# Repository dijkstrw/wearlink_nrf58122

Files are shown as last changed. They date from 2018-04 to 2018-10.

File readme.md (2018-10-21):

# Wearlink v2

## Introduction

While looking for a new winter coat I stumbled on a Taiwanese manufacturer
selling a black and blue winter coat with keys on the sleeve.

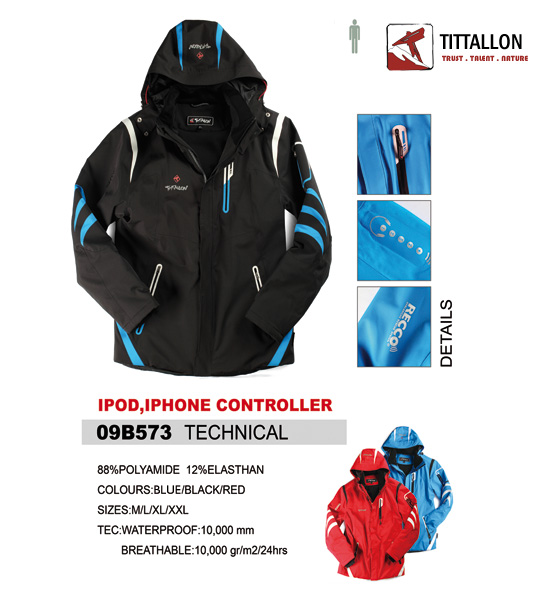
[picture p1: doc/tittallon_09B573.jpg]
Coat and keys


The keys legend betray their intended purpose: volume control, play/pause and
forward/reverse. I listen to podcasts on my android phone in the car and on the
bike, and this would make a great way to control those even when wearing
gloves!

It turns out that the real keypad is glued to the inside of the sleeve, just
under the outer coat layers. A ruggedized two-wire cable connected the keypad
to a 2.5mm TRS in the left chest pocket.

The keypad is manufactured by [FibreTronic](http://fibretronic.com) under the
moniker connectedwear. They sell a range of keypads (my coat has the
[KP2-5SH](http://fibretronic.com/connectedwear/KP25SH) ) and a range of
controllers that can be connected to the keypad. Naturally none of their
controllers work for me. A couple of years I built my
[first controller](https://github.com/dijkstrw/wearlink), and this project is
an update of that design with these requirements:

* No wiring between controller and phone. Making reliable connections between
  flexible wire and hard connectors is a hard problem. I have had to replace
  the connections many times, and have not found a good way to make them last
  years when wires can flex due to walking.

* No wiring means internal battery -- be frugal in power consumption.

* Default interface to the phone. Ideally no programming on the phone, because
  this somewhat guarantees project longevity.

## My design

A controller that pretends to be a usb keyboard and emits multimedia keys for
keypresses. Bluetooth is used to eliminate wires, and the mcu and pcb has been
designed for low power operation to make that battery go for months. I had
heard good things about Nordic, and went with the
[nRF51822](https://www.nordicsemi.com/eng/Products/Bluetooth-low-energy/nRF51822)
because:

* ARM Cortex M0

* Bluetooth Low Energy

* 128k flash at entry level (but read on)

* Onboard regulators, with a supply range between 1.8 and 3.6V

* JTAG programming using a four wire interface

### nRF51822

BLE is implemented using a soft-core that lives in the first half of the
flash. Your application configures the soft-core structures to get the type of
BLE interface you want, and the soft-core will call event-handlers to indicate
radio or hardware events.

The nRF51822 needs an antenna and careful layout. There are also ready made
boards that can be used as complete dropin modules, we use the S4AT here.

### ADC configuration / wakeup

Fibretronics wearlink is a string of push button (no) switches individually in
series with a resistor. When no button is pressed it is open circuit. When one
button is pressed, the resistance corresponding to that key is present between
the two feed wires.

Running the ADC will cause it to sample. Sampling looks like an input impedance
of ~390k, so to spare the battery the ADC needs to run only when BLE is
active. Q1 is used to make nice detectable falling edges at keypress to ensure
wakeup when not in a BLE conversation.

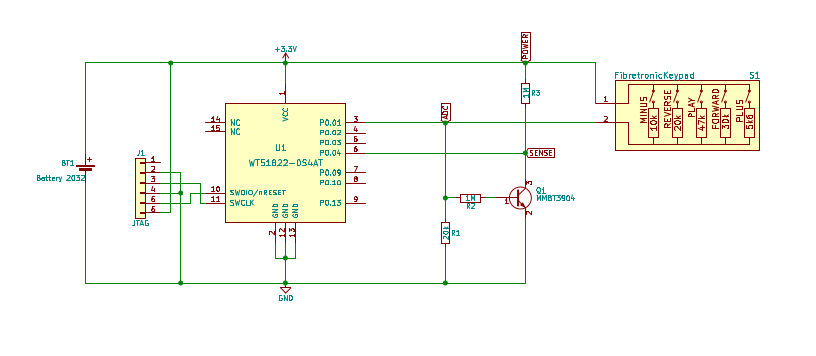
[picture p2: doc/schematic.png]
Kicad schematic


As the battery discharges our ADC input voltage will drop also. This is
compensated for by periodically measuring the battery voltage and taking that
into account when determining keys pressed.

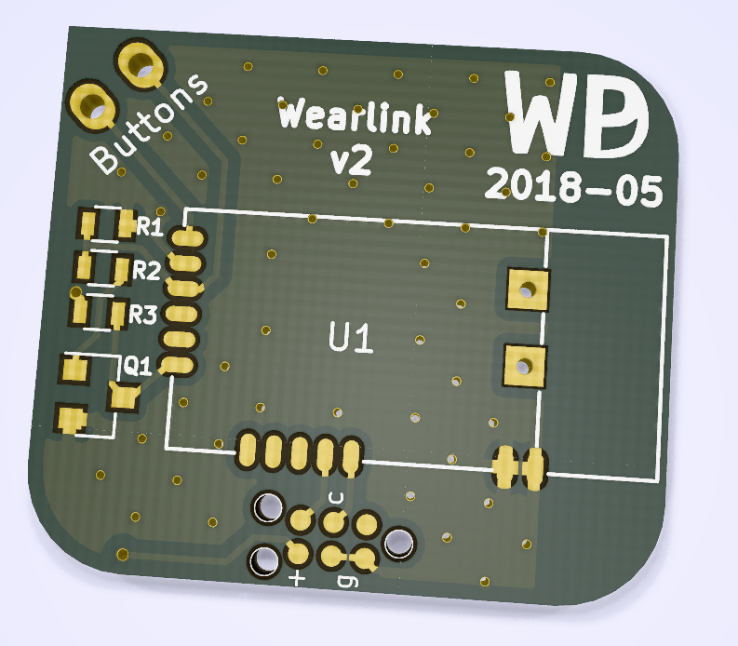
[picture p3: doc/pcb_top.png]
Top

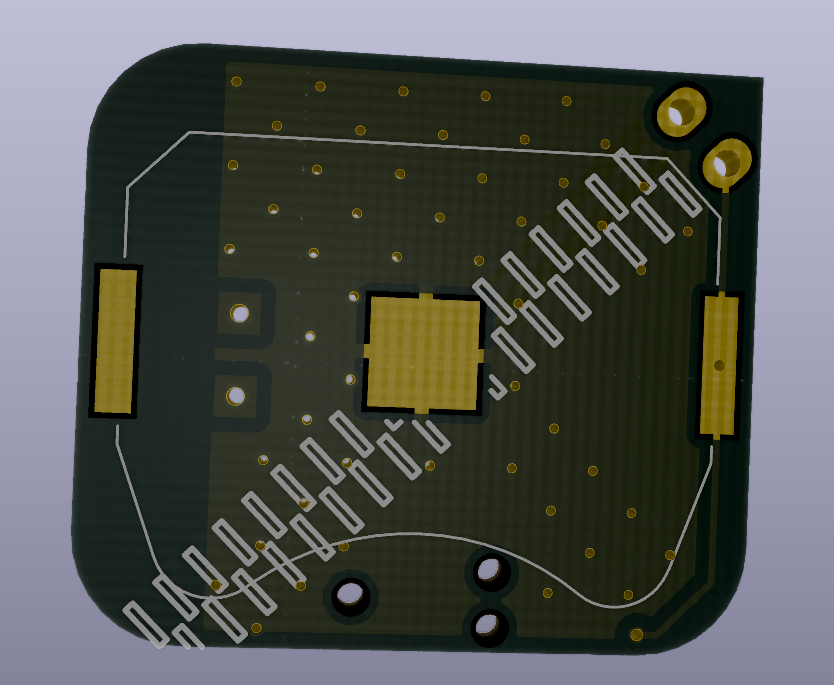
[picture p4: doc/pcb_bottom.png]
Bottom


Note that a TagConnect header is used for JTAG.

### BLE bonding

BLE pairing is stored in flash and reused at next bootup. To make the
controller forget all pairings press key combination PLAY, PLAY, PLAY, VOLUME
DOWN, VOLUME DOWN, VOLUME UP, VOLUME UP directly after controller wakeup.

## Directory structure

* `config` - board configuration files that define clock and peripheral
  configuration for the nrf51. Also the place where the linker file lives

* `doc` - pdf repository for used boards and ics

* `nrf51_sdk_10_0_0` - Download the [SDK](https://developer.nordicsemi.com/nRF5_SDK/nRF51_SDK_v10.x.x/nRF51_SDK_10.0.0_dc26b5e.zip) from Nordic and unzip here

* `schematic` - board schematic and pcb in Kicad

## Next time

* Current nRF51 carrier (S4AT) does not have a LXFT, so even more power can be saved
  next time by choosing or designing a board that does.

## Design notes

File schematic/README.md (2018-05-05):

WT51822-0S4AT taken from https://github.com/cyrozap/KiCad

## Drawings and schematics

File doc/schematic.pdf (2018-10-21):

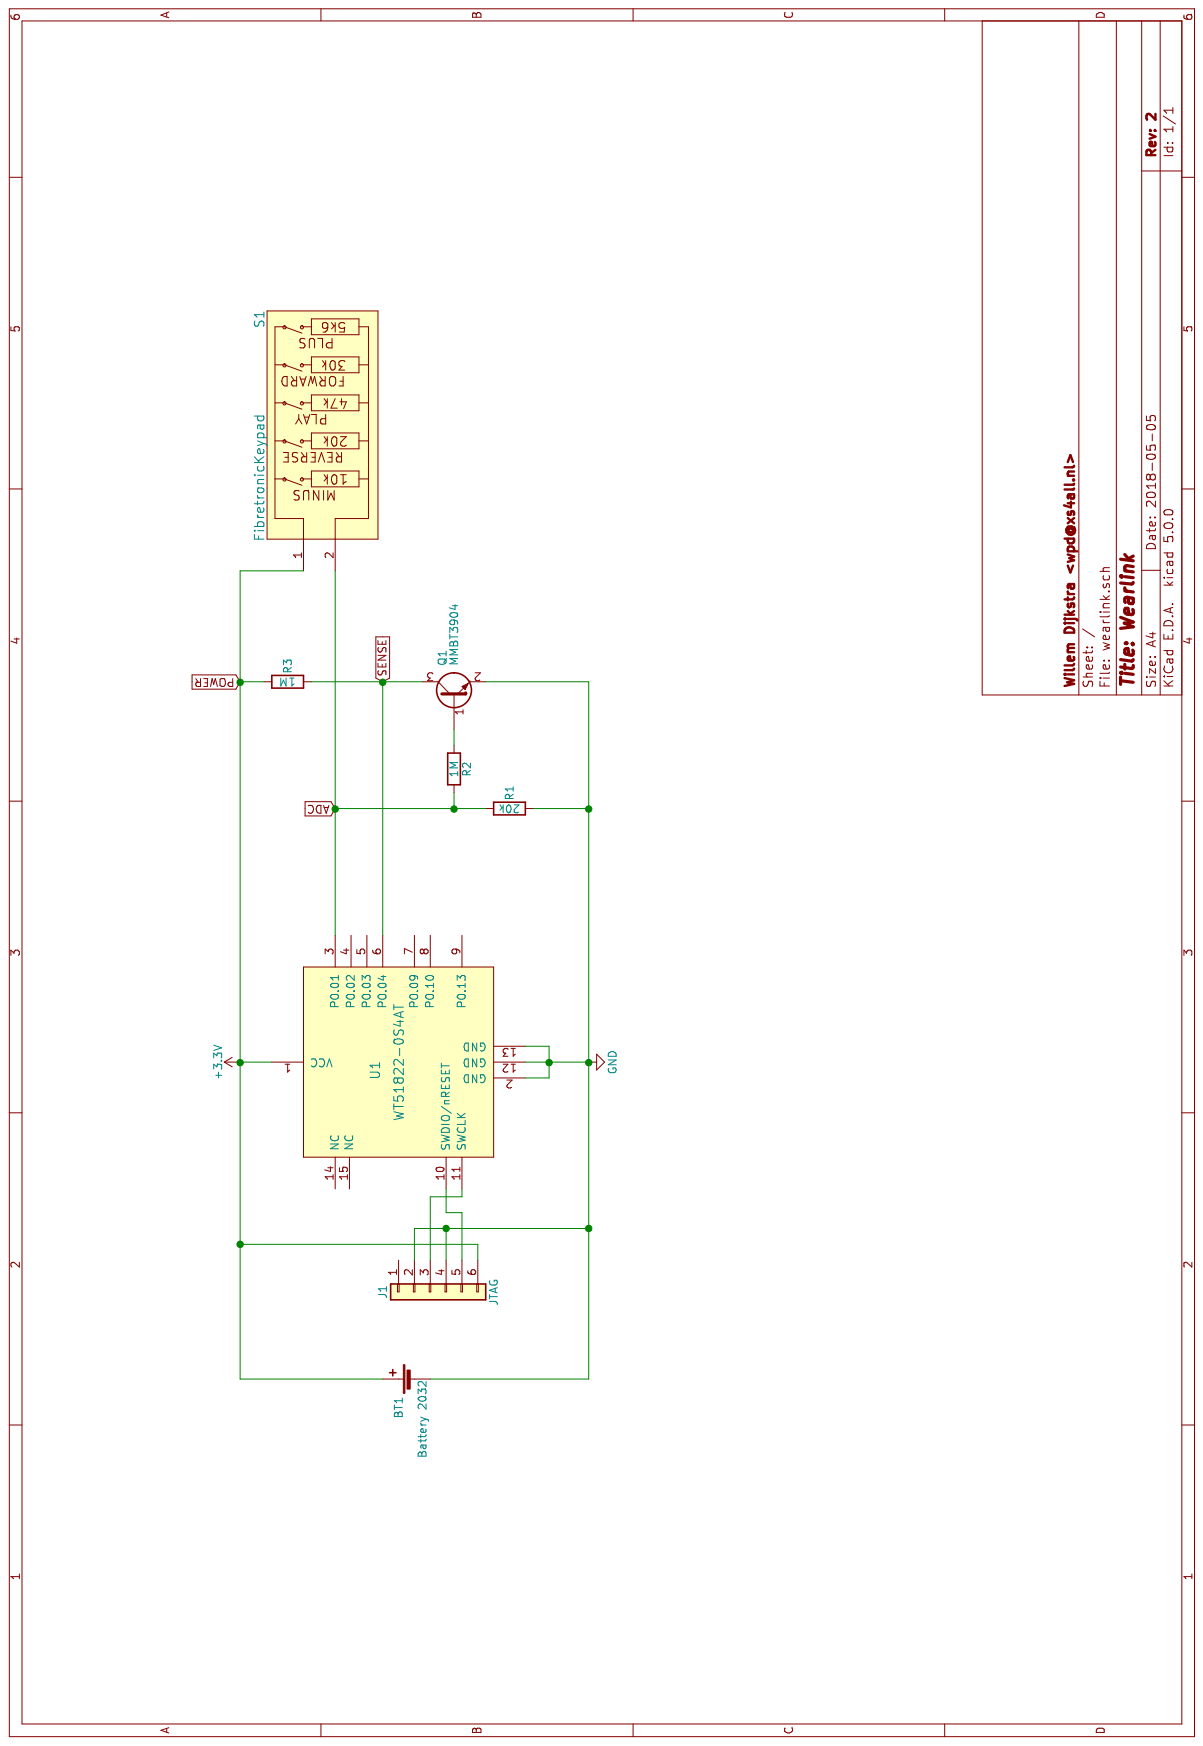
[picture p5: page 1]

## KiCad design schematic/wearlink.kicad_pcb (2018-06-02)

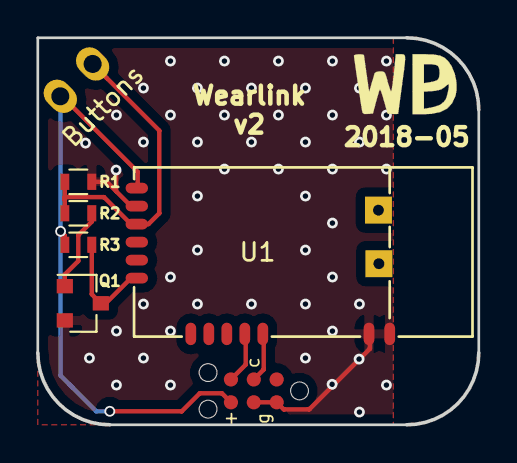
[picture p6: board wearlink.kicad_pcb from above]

Board: 2 copper layers, 24.5 x 21.5 mm, 8 parts (1 on the bottom side), 7 nets.

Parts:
BT1: Battery 2032; Keystone_3034_1x20mm-CoinCell
Buttons: FibretronicKeypad
J1: JTAG; TC2030-IDC-NL
Q1: MMBT3904; SOT-23
R1: 20k; R_0603
R2, R3: 1M; R_0603
U1: WT51822-0S4AT

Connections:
ADC: Buttons.2, R1.1, R2.2, U1.3
GND: BT1.2, J1.2, J1.4, Q1.2, R1.2, U1.2, U1.12, U1.13
unnamed: J1.3, U1.11
unnamed: J1.5, U1.10
unnamed: Q1.1, R2.1
POWER: BT1.1, Buttons.1, J1.6, R3.1, U1.1
SENSE: Q1.3, R3.2, U1.6

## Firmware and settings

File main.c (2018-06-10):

/* Copyright (c) 2018 Willem Dijkstra. All Rights Reserved.
 *
 * Consumer keys (media keys) using nrf51822 and Nordic SDK 10.0.0
 *
 * based on Nordic's ble_sdk_app_hids_keyboard_main sample file.
 *
 */

/* Copyright (c) 2012 Nordic Semiconductor. All Rights Reserved.
 *
 * The information contained herein is property of Nordic Semiconductor ASA.
 * Terms and conditions of usage are described in detail in NORDIC
 * SEMICONDUCTOR STANDARD SOFTWARE LICENSE AGREEMENT.
 *
 * Licensees are granted free, non-transferable use of the information. NO
 * WARRANTY of ANY KIND is provided. This heading must NOT be removed from
 * the file.
 *
 */

#include <stdint.h>
#include <string.h>
#include "nordic_common.h"
#include "nrf.h"
#include "nrf_adc.h"
#include "nrf_assert.h"
#include "nrf_gpio.h"
#include "nrf_drv_gpiote.h"
#include "app_error.h"
#include "ble.h"
#include "ble_hci.h"
#include "ble_srv_common.h"
#include "ble_advertising.h"
#include "ble_advdata.h"
#include "ble_hids.h"
#include "ble_bas.h"
#include "ble_dis.h"
#include "ble_conn_params.h"
#include "bsp.h"
#include "app_scheduler.h"
#include "softdevice_handler_appsh.h"
#include "app_timer_appsh.h"
#include "device_manager.h"
#include "pstorage.h"
#include "app_trace.h"


#define IS_SRVC_CHANGED_CHARACT_PRESENT  0                                              /**< Include or not the service_changed characteristic. if not enabled, the server's database cannot be changed for the lifetime of the device*/

#define INPUT_CCONTROL_KEYS_INDEX	 0
#define INPUT_CC_REP_REF_ID	         1
#define INPUT_CC_REPORT_KEYS_MAX_LEN	 1

#define DEVICE_NAME                      "WearLink"                                     /**< Name of device. Will be included in the advertising data. */
#define MANUFACTURER_NAME                "Dijkstra.xyz"                                 /**< Manufacturer. Will be passed to Device Information Service. */

#define APP_TIMER_PRESCALER              0                                              /**< Value of the RTC1 PRESCALER register. */
#define APP_TIMER_OP_QUEUE_SIZE          4                                              /**< Size of timer operation queues. */

#define BATTERY_LEVEL_MEAS_INTERVAL      APP_TIMER_TICKS(120000, APP_TIMER_PRESCALER)   /**< Battery level measurement interval (ticks). */
#define MAX_IDLE_BATTERY_MEAS            10                                             /**< Maximum idle battery measurement intervals until autosleep */

#define ADC_MEAS_INTERVAL                APP_TIMER_TICKS(30, APP_TIMER_PRESCALER)

#define PNP_ID_VENDOR_ID_SOURCE          0x02                                           /**< Vendor ID Source. */
#define PNP_ID_VENDOR_ID                 0x1915                                         /**< Vendor ID. */
#define PNP_ID_PRODUCT_ID                0xEEEE                                         /**< Product ID. */
#define PNP_ID_PRODUCT_VERSION           0x0001                                         /**< Product Version. */

#define APP_ADV_FAST_INTERVAL            0x0028                                         /**< Fast advertising interval (in units of 0.625 ms. This value corresponds to 25 ms.). */
#define APP_ADV_SLOW_INTERVAL            0x0C80                                         /**< Slow advertising interval (in units of 0.625 ms. This value corrsponds to 2 seconds). */
#define APP_ADV_FAST_TIMEOUT             30                                             /**< The duration of the fast advertising period (in seconds). */
#define APP_ADV_SLOW_TIMEOUT             30                                             /**< The duration of the slow advertising period (in seconds). */

/*lint -emacro(524, MIN_CONN_INTERVAL) // Loss of precision */
#define MIN_CONN_INTERVAL                MSEC_TO_UNITS(7.5, UNIT_1_25_MS)               /**< Minimum connection interval (7.5 ms) */
#define MAX_CONN_INTERVAL                MSEC_TO_UNITS(30, UNIT_1_25_MS)                /**< Maximum connection interval (30 ms). */
#define SLAVE_LATENCY                    6                                              /**< Slave latency. */
#define CONN_SUP_TIMEOUT                 MSEC_TO_UNITS(430, UNIT_10_MS)                 /**< Connection supervisory timeout (430 ms). */

#define FIRST_CONN_PARAMS_UPDATE_DELAY   APP_TIMER_TICKS(5000, APP_TIMER_PRESCALER)     /**< Time from initiating event (connect or start of notification) to first time sd_ble_gap_conn_param_update is called (5 seconds). */
#define NEXT_CONN_PARAMS_UPDATE_DELAY    APP_TIMER_TICKS(30000, APP_TIMER_PRESCALER)    /**< Time between each call to sd_ble_gap_conn_param_update after the first call (30 seconds). */
#define MAX_CONN_PARAMS_UPDATE_COUNT     3                                              /**< Number of attempts before giving up the connection parameter negotiation. */

#define SEC_PARAM_BOND                   1                                              /**< Perform bonding. */
#define SEC_PARAM_MITM                   0                                              /**< Man In The Middle protection not required. */
#define SEC_PARAM_IO_CAPABILITIES        BLE_GAP_IO_CAPS_NONE                           /**< No I/O capabilities. */
#define SEC_PARAM_OOB                    0                                              /**< Out Of Band data not available. */
#define SEC_PARAM_MIN_KEY_SIZE           7                                              /**< Minimum encryption key size. */
#define SEC_PARAM_MAX_KEY_SIZE           16                                             /**< Maximum encryption key size. */

#define APP_FEATURE_NOT_SUPPORTED       BLE_GATT_STATUS_ATTERR_APP_BEGIN + 2            /**< Reply when unsupported features are requested. */

#define BASE_USB_HID_SPEC_VERSION        0x0101                                         /**< Version number of base USB HID Specification implemented by this application. */

#define DEAD_BEEF                        0xDEADBEEF                                     /**< Value used as error code on stack dump, can be used to identify stack location on stack unwind. */

#define SCHED_MAX_EVENT_DATA_SIZE        MAX(APP_TIMER_SCHED_EVT_SIZE,\
                                             BLE_STACK_HANDLER_SCHED_EVT_SIZE)          /**< Maximum size of scheduler events. */
#define SCHED_QUEUE_SIZE                 10                                             /**< Maximum number of events in the scheduler queue. */

#define KEYPAD_ADC_PIN                    NRF_ADC_CONFIG_INPUT_2                        /**< Pin P0.01 */
#define KEYPAD_SENSE_PIN                  4
#define KEYPAD_NUMKEYS                    5

#define KEYPAD_COMBINATIONS               1
#define KEYPAD_COMBINATION_MAXLEN         10

typedef enum
{
    BLE_NO_ADV,               /**< No advertising running. */
    BLE_DIRECTED_ADV,         /**< Direct advertising to the latest central. */
    BLE_FAST_ADV_WHITELIST,   /**< Advertising with whitelist. */
    BLE_FAST_ADV,             /**< Fast advertising running. */
    BLE_SLOW_ADV,             /**< Slow advertising running. */
    BLE_SLEEP,                /**< Go to system-off. */
} ble_advertising_mode_t;

typedef enum
{
    ADC_MODE_KEYPAD,          /* ADC is configured for keypad */
    ADC_MODE_BATTERY,         /* ADC is configured to measure battery */
} adc_mode_t;

static ble_hids_t                        m_hids;                                        /**< Structure used to identify the HID service. */
static ble_bas_t                         m_bas;                                         /**< Structure used to identify the battery service. */

static uint16_t                          m_conn_handle = BLE_CONN_HANDLE_INVALID;       /**< Handle of the current connection. */

APP_TIMER_DEF(m_battery_timer_id);                                                      /**< Battery timer. */

APP_TIMER_DEF(m_adc_timer_id);

static dm_application_instance_t         m_app_handle;                                  /**< Application identifier allocated by device manager. */
static dm_handle_t                       m_bonded_peer_handle;                          /**< Device reference handle to the current bonded central. */

static ble_uuid_t m_adv_uuids[] = {{BLE_UUID_HUMAN_INTERFACE_DEVICE_SERVICE, BLE_UUID_TYPE_BLE}};

static adc_mode_t                        adc_mode;
volatile int32_t                         adc_sample;
static uint8_t                           battery_level;
static float                             battery_correction = 1.0;
static uint8_t                           idle_counter = 0;
static uint8_t                           start_key = 0;

/*
  Fibretronics wearlink is a string of push button (no) switches individually
  in series with a resistor. When no button is pressed it is open
  circuit. When one button is pressed, the resistance corresponding to that
  key is present between the two feed wires.

  To determine the value for the adc we calculate ideal adc reading based on
  the known/measured resistance per button.

  Additional wrinkles;
  - ADC reference is VBG = 1.2V
  - ADC prescaling = 1/3
  - ADC input impendance is ~390k
  - ADC sampling time is 20us @ 8 bits, 68us @ 10 bit

  Schematic:

   Vcc--Rk---x----Rl--gnd
             |
            Ra
             |
           Vref/2

   Where:
   Rk = key resistance
   Rl = limit or load resistance, makes a Rk + Rl load when not sampling
   Ra = the adc impedance at sampling time
   Ua = voltage at point x

   Ik = Il + Ia = Vcc / Rk
   Ia = (Ua - (Vref / 2)) / Rain
   Il = Ua / Rl

   Solve for Ua: Ua = (-Vcc - ((Vref / 2) / Ra)) / (-1 - (Rk / Ra) - (Rk / Rl))

  #+ORGTBL: SEND keymarks orgtbl-to-generic :lstart "   { " :lend " }," :sep ", ", :skip 4 :skipcols (3 4 5 6 7)
  | ! | Key                           |       Rk |         Uau |      Ua |   Vscaled |      Adc |   A-D% |    A+D% |
  |   |                               |          |   unsampled | sampled |           |          |        |         |
  |---+-------------------------------+----------+-------------+---------+-----------+----------+--------+---------|
  | # | RELEASE_KEY                   | 10000000 |       0.007 |   0.036 |     0.012 |        3 |      3 |       3 |
  | # | CONSUMER_CTRL_VOL_DW          |    10000 |       2.400 |   2.370 |     0.790 |      169 |    161 |     177 |
  | # | CONSUMER_CTRL_SCAN_PREV_TRACK |    20000 |       1.800 |   1.770 |     0.590 |      126 |    120 |     132 |
  | # | CONSUMER_CTRL_PLAY            |    47000 |       1.075 |   1.058 |     0.353 |       75 |     71 |      79 |
  | # | CONSUMER_CTRL_SCAN_NEXT_TRACK |    30000 |       1.440 |   1.415 |     0.472 |      101 |     96 |     106 |
  | # | CONSUMER_CTRL_VOL_UP          |     5600 |       2.812 |   2.788 |     0.929 |      198 |    188 |     208 |
  |---+-------------------------------+----------+-------------+---------+-----------+----------+--------+---------|
  | $ | Vcc=3.6                       | Rl=20000 | Rain=389200 |         | scale=1/3 | Vref=1.2 | bits=8 | dev=.05 |
  #+TBLFM: $4=($Rl/($Rk+$Rl))*$Vcc;%.3f::$5=(-(($Vref/2)*$3)/$Rain-$Vcc)/((-$3/$Rain)-($3/$Rl)-1);%.3f::$6=$Ua*$scale;%.3f::$7=$Vscaled/($Vref/2^$bits);%.0f::$8=max($7-($dev*$7),0);%.0f::$9=min($7+($dev*$7),2^$bits);%0.f

  Note that the measurement is compared to the internal reference, and that the
  supply voltage will slowly drop due to battery discharge. We take this into
  account by adjusting the adc read voltage by a battery level correction.
*/

#define ADC_BATTERY_3V6  (1<<8)

typedef enum
{
    RELEASE_KEY                     = 0x00,
    CONSUMER_CTRL_PLAY              = 0x01,
    CONSUMER_CTRL_ALCCC             = 0x02,
    CONSUMER_CTRL_SCAN_NEXT_TRACK   = 0x04,
    CONSUMER_CTRL_SCAN_PREV_TRACK   = 0x08,
    CONSUMER_CTRL_VOL_DW            = 0x10,
    CONSUMER_CTRL_VOL_UP            = 0x20,
    CONSUMER_CTRL_AC_FORWARD        = 0x40,
    CONSUMER_CTRL_AC_BACK           = 0x80,
} consumer_control_t;

const struct keymark {
    uint8_t key;
    uint8_t low;
    uint8_t high;
} keymark[KEYPAD_NUMKEYS] = {
/* BEGIN RECEIVE ORGTBL keymarks */
   { CONSUMER_CTRL_VOL_DW,          161, 177 },
   { CONSUMER_CTRL_SCAN_PREV_TRACK, 120, 132 },
   { CONSUMER_CTRL_PLAY,             71,  79 },
   { CONSUMER_CTRL_SCAN_NEXT_TRACK,  96, 106 },
   { CONSUMER_CTRL_VOL_UP,          188, 208 },
/* END RECEIVE ORGTBL keymarks */
};

typedef enum
{
    NO_ACTION,
    ACTION_ERASE_BONDS
} keycombo_action_t;

struct keycombo {
    uint8_t len;
    uint8_t cur;
    keycombo_action_t action;
    uint8_t keys[KEYPAD_COMBINATION_MAXLEN];
} keycombo[KEYPAD_COMBINATIONS] = {
    {7, 0, ACTION_ERASE_BONDS,
     { CONSUMER_CTRL_PLAY,
       CONSUMER_CTRL_PLAY,
       CONSUMER_CTRL_PLAY,
       CONSUMER_CTRL_VOL_DW,
       CONSUMER_CTRL_VOL_DW,
       CONSUMER_CTRL_VOL_UP,
       CONSUMER_CTRL_VOL_UP }},
};

static uint8_t adc_process_battery_measurement(int32_t sample);
static uint8_t adc_process_keypad_measurement(int32_t sample);
static void adc_init(adc_mode_t mode_req);
static void adc_timeout_handler(void *p_context);
static void keypad_combo_handler(uint8_t key);
static void on_hids_evt(ble_hids_t * p_hids, ble_hids_evt_t * p_evt);

/*
 * Fibretronics wearlink is a string of push button (no) switches individually
 * in series with a resistor. When no button is pressed it is open
 * circuit. When one button is pressed, the resistance corresponding to that
 * key is present between the two feed wires.
 *
 * To determine the value for the adc we calculate ideal adc reading based on
 * the known/measured resistance per button.
 *
 */

/**@brief Callback function for asserts in the SoftDevice.
 *
 * @details This function will be called in case of an assert in the SoftDevice.
 *
 * @warning This handler is an example only and does not fit a final product. You need to analyze
 *          how your product is supposed to react in case of Assert.
 * @warning On assert from the SoftDevice, the system can only recover on reset.
 *
 * @param[in]   line_num   Line number of the failing ASSERT call.
 * @param[in]   file_name  File name of the failing ASSERT call.
 */
void assert_nrf_callback(uint16_t line_num, const uint8_t * p_file_name)
{
    app_error_handler(DEAD_BEEF, line_num, p_file_name);
}


/**@brief Function for handling Service errors.
 *
 * @details A pointer to this function will be passed to each service which may need to inform the
 *          application about an error.
 *
 * @param[in]   nrf_error   Error code containing information about what went wrong.
 */
static void service_error_handler(uint32_t nrf_error)
{
    APP_ERROR_HANDLER(nrf_error);
}


/**@brief Function for handling advertising errors.
 *
 * @param[in] nrf_error  Error code containing information about what went wrong.
 */
static void ble_advertising_error_handler(uint32_t nrf_error)
{
    APP_ERROR_HANDLER(nrf_error);
}


/**@brief Function for handling the Battery measurement timer timeout.
 *
 * @details This function will be called each time the battery level measurement timer expires.
 *
 * @param[in]   p_context   Pointer used for passing some arbitrary information (context) from the
 *                          app_start_timer() call to the timeout handler.
 */
static void battery_level_meas_timeout_handler(void * p_context)
{
    UNUSED_PARAMETER(p_context);

    if (! nrf_adc_is_busy()) {
        adc_init(ADC_MODE_BATTERY);
        nrf_adc_start();
        app_timer_start(m_adc_timer_id, ADC_MEAS_INTERVAL, NULL);
    }
}

/**@brief Function for the Timer initialization.
 *
 * @details Initializes the timer module.
 */
static void timers_init(void)
{
    uint32_t err_code;

    // Initialize timer module, making it use the scheduler.
    APP_TIMER_APPSH_INIT(APP_TIMER_PRESCALER, APP_TIMER_OP_QUEUE_SIZE, true);

    // Create battery timer.
    err_code = app_timer_create(&m_battery_timer_id,
                                APP_TIMER_MODE_REPEATED,
                                battery_level_meas_timeout_handler);
    APP_ERROR_CHECK(err_code);

    // Create adc timer
    err_code = app_timer_create(&m_adc_timer_id,
                                APP_TIMER_MODE_SINGLE_SHOT,
                                adc_timeout_handler);
    APP_ERROR_CHECK(err_code);
}


/**@brief Function for the GAP initialization.
 *
 * @details This function sets up all the necessary GAP (Generic Access Profile) parameters of the
 *          device including the device name, appearance, and the preferred connection parameters.
 */
static void gap_params_init(void)
{
    uint32_t                err_code;
    ble_gap_conn_params_t   gap_conn_params;
    ble_gap_conn_sec_mode_t sec_mode;

    BLE_GAP_CONN_SEC_MODE_SET_OPEN(&sec_mode);

    err_code = sd_ble_gap_device_name_set(&sec_mode,
                                          (const uint8_t *)DEVICE_NAME,
                                          strlen(DEVICE_NAME));
    APP_ERROR_CHECK(err_code);

    err_code = sd_ble_gap_appearance_set(BLE_APPEARANCE_GENERIC_HID);
    APP_ERROR_CHECK(err_code);

    memset(&gap_conn_params, 0, sizeof(gap_conn_params));

    gap_conn_params.min_conn_interval = MIN_CONN_INTERVAL;
    gap_conn_params.max_conn_interval = MAX_CONN_INTERVAL;
    gap_conn_params.slave_latency     = SLAVE_LATENCY;
    gap_conn_params.conn_sup_timeout  = CONN_SUP_TIMEOUT;

    err_code = sd_ble_gap_ppcp_set(&gap_conn_params);
    APP_ERROR_CHECK(err_code);
}


/**@brief Function for initializing Device Information Service.
 */
static void dis_init(void)
{
    uint32_t         err_code;
    ble_dis_init_t   dis_init_obj;
    ble_dis_pnp_id_t pnp_id;

    pnp_id.vendor_id_source = PNP_ID_VENDOR_ID_SOURCE;
    pnp_id.vendor_id        = PNP_ID_VENDOR_ID;
    pnp_id.product_id       = PNP_ID_PRODUCT_ID;
    pnp_id.product_version  = PNP_ID_PRODUCT_VERSION;

    memset(&dis_init_obj, 0, sizeof(dis_init_obj));

    ble_srv_ascii_to_utf8(&dis_init_obj.manufact_name_str, MANUFACTURER_NAME);
    dis_init_obj.p_pnp_id = &pnp_id;

    BLE_GAP_CONN_SEC_MODE_SET_ENC_NO_MITM(&dis_init_obj.dis_attr_md.read_perm);
    BLE_GAP_CONN_SEC_MODE_SET_NO_ACCESS(&dis_init_obj.dis_attr_md.write_perm);

    err_code = ble_dis_init(&dis_init_obj);
    APP_ERROR_CHECK(err_code);
}


/**@brief Function for initializing Battery Service.
 */
static void bas_init(void)
{
    uint32_t       err_code;
    ble_bas_init_t bas_init_obj;

    memset(&bas_init_obj, 0, sizeof(bas_init_obj));

    bas_init_obj.evt_handler          = NULL;
    bas_init_obj.support_notification = true;
    bas_init_obj.p_report_ref         = NULL;
    bas_init_obj.initial_batt_level   = 100;

    BLE_GAP_CONN_SEC_MODE_SET_ENC_NO_MITM(&bas_init_obj.battery_level_char_attr_md.cccd_write_perm);
    BLE_GAP_CONN_SEC_MODE_SET_ENC_NO_MITM(&bas_init_obj.battery_level_char_attr_md.read_perm);
    BLE_GAP_CONN_SEC_MODE_SET_NO_ACCESS(&bas_init_obj.battery_level_char_attr_md.write_perm);

    BLE_GAP_CONN_SEC_MODE_SET_ENC_NO_MITM(&bas_init_obj.battery_level_report_read_perm);

    err_code = ble_bas_init(&m_bas, &bas_init_obj);
    APP_ERROR_CHECK(err_code);
}
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
int main(void)
{
    uint32_t err_code;

    // Initialize.
    app_trace_init();
    keypad_boot_buttons();

    timers_init();
    leds_init();

    keypad_keypress_detection_init();

    ble_stack_init();
    scheduler_init();
    device_manager_init();
    gap_params_init();
    advertising_init();
    services_init();
    conn_params_init();

    // Start execution.
    timers_start();
    err_code = ble_advertising_start(BLE_ADV_MODE_FAST);
    APP_ERROR_CHECK(err_code);

    // Enter main loop.
    for (;;)
    {
        app_sched_execute();
        power_manage();
    }
}

/**
 * @}
 */

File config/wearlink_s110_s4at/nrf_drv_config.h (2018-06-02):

/* Copyright (c) 2015 Nordic Semiconductor. All Rights Reserved.
 *
 * The information contained herein is property of Nordic Semiconductor ASA.
 * Terms and conditions of usage are described in detail in NORDIC
 * SEMICONDUCTOR STANDARD SOFTWARE LICENSE AGREEMENT.
 *
 * Licensees are granted free, non-transferable use of the information. NO
 * WARRANTY of ANY KIND is provided. This heading must NOT be removed from
 * the file.
 *
 */

#ifndef NRF_DRV_CONFIG_H
#define NRF_DRV_CONFIG_H

/* CLOCK */
#define CLOCK_CONFIG_XTAL_FREQ          NRF_CLOCK_XTALFREQ_Default
#define CLOCK_CONFIG_LF_SRC             NRF_CLOCK_LF_SRC_RC
#define CLOCK_CONFIG_LF_RC_CAL_INTERVAL RC_8000MS_CALIBRATION_INTERVAL
#define CLOCK_CONFIG_IRQ_PRIORITY       APP_IRQ_PRIORITY_LOW

/* GPIOTE */
#define GPIOTE_ENABLED 1

#if (GPIOTE_ENABLED == 1)
#define GPIOTE_CONFIG_USE_SWI_EGU false
#define GPIOTE_CONFIG_IRQ_PRIORITY APP_IRQ_PRIORITY_LOW
#define GPIOTE_CONFIG_NUM_OF_LOW_POWER_EVENTS 4
#endif

/* TIMER */
#define TIMER0_ENABLED 0

#if (TIMER0_ENABLED == 1)
#define TIMER0_CONFIG_FREQUENCY    NRF_TIMER_FREQ_16MHz
#define TIMER0_CONFIG_MODE         TIMER_MODE_MODE_Timer
#define TIMER0_CONFIG_BIT_WIDTH    TIMER_BITMODE_BITMODE_32Bit
#define TIMER0_CONFIG_IRQ_PRIORITY APP_IRQ_PRIORITY_LOW

#define TIMER0_INSTANCE_INDEX      0
#endif

#define TIMER1_ENABLED 0

#if (TIMER1_ENABLED == 1)
#define TIMER1_CONFIG_FREQUENCY    NRF_TIMER_FREQ_16MHz
#define TIMER1_CONFIG_MODE         TIMER_MODE_MODE_Timer
#define TIMER1_CONFIG_BIT_WIDTH    TIMER_BITMODE_BITMODE_16Bit
#define TIMER1_CONFIG_IRQ_PRIORITY APP_IRQ_PRIORITY_LOW

#define TIMER1_INSTANCE_INDEX      (TIMER0_ENABLED)
#endif
 
#define TIMER2_ENABLED 0

#if (TIMER2_ENABLED == 1)
#define TIMER2_CONFIG_FREQUENCY    NRF_TIMER_FREQ_16MHz
#define TIMER2_CONFIG_MODE         TIMER_MODE_MODE_Timer
#define TIMER2_CONFIG_BIT_WIDTH    TIMER_BITMODE_BITMODE_16Bit
#define TIMER2_CONFIG_IRQ_PRIORITY APP_IRQ_PRIORITY_LOW

#define TIMER2_INSTANCE_INDEX      (TIMER1_ENABLED+TIMER0_ENABLED)
#endif

#define TIMER3_ENABLED 0

#if (TIMER3_ENABLED == 1)
#define TIMER3_CONFIG_FREQUENCY    NRF_TIMER_FREQ_16MHz
#define TIMER3_CONFIG_MODE         TIMER_MODE_MODE_Timer
#define TIMER3_CONFIG_BIT_WIDTH    TIMER_BITMODE_BITMODE_16Bit
#define TIMER3_CONFIG_IRQ_PRIORITY APP_IRQ_PRIORITY_LOW

#define TIMER3_INSTANCE_INDEX      (TIMER2_ENABLED+TIMER1_ENABLED+TIMER0_ENABLED)
#endif

#define TIMER4_ENABLED 0

#if (TIMER4_ENABLED == 1)
#define TIMER4_CONFIG_FREQUENCY    NRF_TIMER_FREQ_16MHz
#define TIMER4_CONFIG_MODE         TIMER_MODE_MODE_Timer
#define TIMER4_CONFIG_BIT_WIDTH    TIMER_BITMODE_BITMODE_16Bit
#define TIMER4_CONFIG_IRQ_PRIORITY APP_IRQ_PRIORITY_LOW

#define TIMER4_INSTANCE_INDEX      (TIMER3_ENABLED+TIMER2_ENABLED+TIMER1_ENABLED+TIMER0_ENABLED)
#endif


#define TIMER_COUNT (TIMER0_ENABLED + TIMER1_ENABLED + TIMER2_ENABLED + TIMER3_ENABLED + TIMER4_ENABLED)

/* RTC */
#define RTC0_ENABLED 0

#if (RTC0_ENABLED == 1)
#define RTC0_CONFIG_FREQUENCY    32678
#define RTC0_CONFIG_IRQ_PRIORITY APP_IRQ_PRIORITY_LOW
#define RTC0_CONFIG_RELIABLE     false

#define RTC0_INSTANCE_INDEX      0
#endif

#define RTC1_ENABLED 0

#if (RTC1_ENABLED == 1)
#define RTC1_CONFIG_FREQUENCY    32768
#define RTC1_CONFIG_IRQ_PRIORITY APP_IRQ_PRIORITY_LOW
#define RTC1_CONFIG_RELIABLE     false

#define RTC1_INSTANCE_INDEX      (RTC0_ENABLED)
#endif

#define RTC_COUNT                (RTC0_ENABLED+RTC1_ENABLED)

#define NRF_MAXIMUM_LATENCY_US 2000

/* RNG */
#define RNG_ENABLED 0

#if (RNG_ENABLED == 1)
#define RNG_CONFIG_ERROR_CORRECTION true
#define RNG_CONFIG_POOL_SIZE        8
#define RNG_CONFIG_IRQ_PRIORITY     APP_IRQ_PRIORITY_LOW
#endif

/* SPI */
#define SPI0_ENABLED 0

#if (SPI0_ENABLED == 1)
#define SPI0_USE_EASY_DMA 0

#define SPI0_CONFIG_SCK_PIN         2
#define SPI0_CONFIG_MOSI_PIN        3
#define SPI0_CONFIG_MISO_PIN        4
#define SPI0_CONFIG_IRQ_PRIORITY    APP_IRQ_PRIORITY_LOW

#define SPI0_INSTANCE_INDEX 0
#endif

#define SPI1_ENABLED 0

#if (SPI1_ENABLED == 1)
#define SPI1_USE_EASY_DMA 0

#define SPI1_CONFIG_SCK_PIN         2
#define SPI1_CONFIG_MOSI_PIN        3
#define SPI1_CONFIG_MISO_PIN        4
#define SPI1_CONFIG_IRQ_PRIORITY    APP_IRQ_PRIORITY_LOW

#define SPI1_INSTANCE_INDEX (SPI0_ENABLED)
#endif

#define SPI2_ENABLED 0

#if (SPI2_ENABLED == 1)
#define SPI2_USE_EASY_DMA 0

#define SPI2_CONFIG_SCK_PIN         2
#define SPI2_CONFIG_MOSI_PIN        3
#define SPI2_CONFIG_MISO_PIN        4
#define SPI2_CONFIG_IRQ_PRIORITY    APP_IRQ_PRIORITY_LOW

#define SPI2_INSTANCE_INDEX (SPI0_ENABLED + SPI1_ENABLED)
#endif

#define SPI_COUNT   (SPI0_ENABLED + SPI1_ENABLED + SPI2_ENABLED)

/* SPIS */
#define SPIS0_ENABLED 0

#if (SPIS0_ENABLED == 1)
#define SPIS0_CONFIG_SCK_PIN         2
#define SPIS0_CONFIG_MOSI_PIN        3
#define SPIS0_CONFIG_MISO_PIN        4
#define SPIS0_CONFIG_IRQ_PRIORITY    APP_IRQ_PRIORITY_LOW

#define SPIS0_INSTANCE_INDEX 0
#endif

#define SPIS1_ENABLED 0
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

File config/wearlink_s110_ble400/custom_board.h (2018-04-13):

/* Copyright (c) 2012 Nordic Semiconductor. All Rights Reserved.
 *
 * The information contained herein is property of Nordic Semiconductor ASA.
 * Terms and conditions of usage are described in detail in NORDIC
 * SEMICONDUCTOR STANDARD SOFTWARE LICENSE AGREEMENT.
 *
 * Licensees are granted free, non-transferable use of the information. NO
 * WARRANTY of ANY KIND is provided. This heading must NOT be removed from
 * the file.
 *
 */
#ifndef WBLE400_H
#define WBLE400_H

#define LED_START      18
#define LED_0          18
#define LED_1          19
#define LED_2          20
#define LED_3          21
#define LED_4          22
#define LED_STOP       22

#define BSP_LED_0      LED_0
#define BSP_LED_1      LED_1
#define BSP_LED_2      LED_2
#define BSP_LED_3      LED_3
#define BSP_LED_4      LED_4

#define BUTTON_START   16
#define BUTTON_0       16
#define BUTTON_1       17
#define BUTTON_STOP    17
#define BUTTON_PULL    NRF_GPIO_PIN_PULLUP

#define BSP_BUTTON_0   BUTTON_0
#define BSP_BUTTON_1   BUTTON_1

#define BUTTONS_NUMBER 2
#define LEDS_NUMBER    5
#define LEDS_INV_MASK  0

#define BSP_BUTTON_0_MASK (1<<BSP_BUTTON_0)
#define BSP_BUTTON_1_MASK (1<<BSP_BUTTON_1)
#define BUTTONS_MASK   (BSP_BUTTON_0_MASK | BSP_BUTTON_1_MASK)

#define BUTTONS_LIST { BUTTON_0, BUTTON_1 }
#define LEDS_LIST { LED_0, LED_1, LED_2, LED_3, LED_4 }

#define BSP_LED_0_MASK    (1<<LED_0)
#define BSP_LED_1_MASK    (1<<LED_1)
#define BSP_LED_2_MASK    (1<<LED_2)
#define BSP_LED_3_MASK    (1<<LED_3)
#define BSP_LED_4_MASK    (1<<LED_4)
#define LEDS_MASK         (BSP_LED_0_MASK | BSP_LED_1_MASK | BSP_LED_2_MASK | BSP_LED_3_MASK | BSP_LED_4_MASK)

#define RX_PIN_NUMBER  11
#define TX_PIN_NUMBER  9
#define CTS_PIN_NUMBER 8
#define RTS_PIN_NUMBER 10
#define HWFC           true

#define SER_CONN_ASSERT_LED_PIN     LED_0

// Low frequency clock source to be used by the SoftDevice
#define NRF_CLOCK_LFCLKSRC      NRF_CLOCK_LFCLKSRC_XTAL_20_PPM

#endif

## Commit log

2017-02-10 its work
    [jlink.cfg]
2017-02-11 Added consumer control
    [jlink.cfg]
2018-04-14 After a full erase this works
    So something about renegotiation is broken and needs to be added. Still,
    I have media keys in android, so this is quite cool already.
    [main.c]
2018-04-15 Added initial adc interaction
    ADC reads AIN2 -> P0.1
2018-04-20 Added powerpin for keypad
2018-04-20 gpiote triggered adc reads
2018-04-22 Added first calculations for adc key values
2018-05-03 Tested enable and adc hardware
2018-05-03 Working prototype
    Next step: decrease current draw :)
2018-05-03 Enabled power save, but adc is broken on wakeup
    [main.c]
2018-05-04 Removed sensorsim, added actual battery measurement
2018-05-05 Battery is vcc, cope with adc change @ discharging
    - sample battery quickly after startup to determine current Vdd
    - set ble battery level as a percentage of 3V6
    - remove remaining app buttons
2018-05-05 Started with schematic
    [wearlink.kicad_pcb, wearlink.sch]
2018-05-05 Added footprints, first route
    Seems a little to spacious..
    [wearlink.kicad_pcb, wearlink.sch]
2018-05-06 Auto sleep also when connected but idle
    After n battery measurement intervals with no other actions happening
    also autosleep to save battery.
2018-05-06 Cleaned up schematic
    Added holes for module
    [wearlink.kicad_pcb]
2018-05-07 Made pcb smaller
    [wearlink.kicad_pcb]
2018-05-11 Verified hole sizes WT51822, more pcb cleanup
    [wearlink.kicad_pcb, wearlink.sch]
2018-05-11 Added via stitching
    [wearlink.kicad_pcb]
2018-05-13 Removed bsp button interaction, added combos
    When no ble connection is active, the device will look for
    keycombos. Only one is defined at this time, and that item will drop all
    known peers in the device manager, breaking active peerings.
2018-06-02 Bugfix: now add boot button in main.c
    [main.c]
2018-06-02 As sent to pcbway 20180517
    [wearlink.kicad_pcb, wearlink.sch]
2018-06-10 Adjust idle timer to 20 mins, add start_key
